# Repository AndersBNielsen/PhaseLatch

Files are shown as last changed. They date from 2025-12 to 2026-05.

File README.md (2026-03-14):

# PhaseLatch

PhaseLatch – 6502-Interfaced High-Speed ADC for Experimental SDR

Blog post & video: https://abnielsen.com/2025/12/24/6502-and-a-20mhz-adc-takes-up-the-challenge/

PhaseLatch is an open-source hardware project that explores how far a classic MOS 6502-class CPU can be pushed into modern signal-processing territory. The board implements a dual-channel, 10-bit, 20 MSPS analog-to-digital converter with a straight binary parallel output, allowing the ADC to be memory-mapped directly onto a 6502 (8 bit) data bus.

Unlike typical SDR designs that rely on high-performance microcontrollers or FPGAs, PhaseLatch intentionally interfaces high-speed conversion hardware with a severely resource-constrained 8-bit CPU. This makes it a platform for experimenting with timing limits, bus contention, memory expansion, and minimalist DSP techniques such as Goertzel tone detection executed entirely on the 6502.

The board is designed as a modular Arduino-shield-style form factor and is intended to stack with the PhaseLoom IQ mixer and the 65uino 6502 system. Direct access to the CPU address, data, and control signals enables single-instruction ADC reads and deterministic sampling under software control.

PhaseLatch is not intended to achieve full theoretical ADC bandwidth on a 6502. Instead, it serves as a practical exploration of real-world limitations, architectural trade-offs, and creative signal-processing approaches on vintage computing hardware.

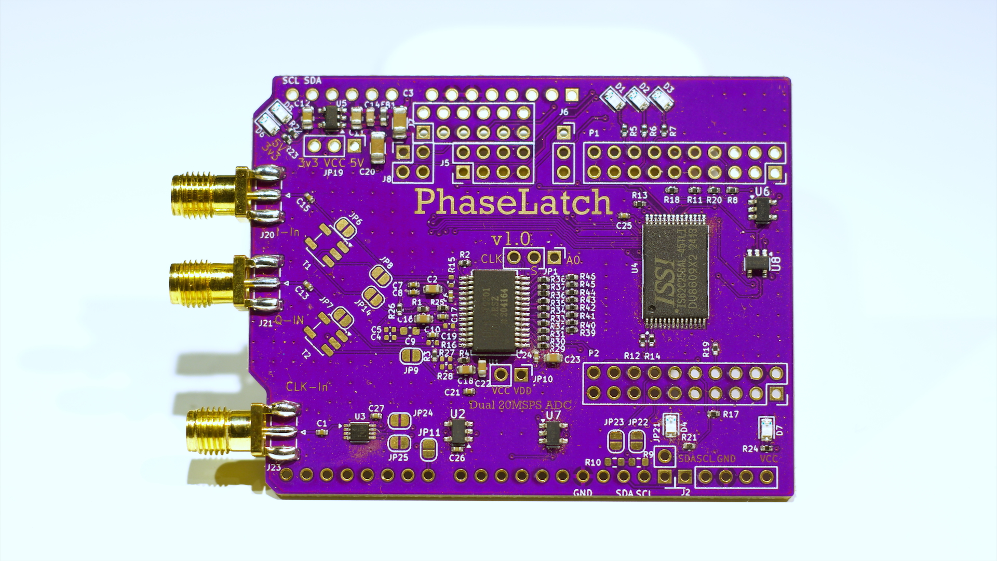
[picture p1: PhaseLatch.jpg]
PhaseLatch board photo


## Purchase

Interested in owning a PhaseLatch?  
[Buy one here](https://www.imania.dk/index.php?cPath=204&sort=5a&language=en).

## How to Use
[6502 source code still lives over on the 65uino project](https://github.com/AndersBNielsen/65uino/)

The main 65uino firmware currently comes with support for the PhaseLatch built in. Time of writing, use the SDR branch. 

To get the full bandwidth out of PhaseLatch, it can also be used with an **FX2LP** USB streaming board instead of the **65uino**.

## Software
The `software/` folder contains the USB streamer firmware + host-side tools for getting PhaseLatch data into SDR software.

- [software/README.md](software/README.md): Overview, build instructions, and a demo cheat sheet.
- [software/firmware/](software/firmware/): FX2/FX2LP firmware (USB streaming).
- [software/host/](software/host/): Host utilities (USB reader, format conversion, DC / IQ correction).
- [software/examples/](software/examples/): Example pipelines (including streaming to `/tmp/iq.fifo` for Gqrx).
- [software/doc/](software/doc/): Notes on wiring and rate planning.

## Using with an FX2LP (USB streaming)
PhaseLatch includes header footprints intended for wiring to an **FX2LP** dev board. The FX2LP provides USB 2.0 high‑speed bulk streaming and acts as the “bridge” from the ADC to a host PC.

At a high level the flow is:
- FX2LP firmware streams raw samples over USB
- host reads via libusb and converts to CF32
- stream is written to `/tmp/iq.fifo` so **Gqrx** can open it

Start with the guide in `software/README.md`, then use `software/examples/pipeline.sh` for a one-command stream to `/tmp/iq.fifo`.

## Getting a PCB

## Production & Manufacturing
- The `jlcpcb/gerber/` folder contains all necessary files for PCB fabrication.
- The `production_files/` folder includes:
  - `BOM-PhaseLatch.csv`: Bill of Materials
  - `CPL-PhaseLatch.csv`: Component Placement List
  - `GERBER-PhaseLatch.zip`: Zipped Gerber files for easy upload

This project is kindly sponsored by JLCPCB. They offer cheap, professional looking PCBs and super fast delivery.

Step 1: Get the gerber file zip package from the /hardware folder

Step 2: Upload to JLCPCB [https://jlcpcb.com/?from=Anders_N](https://jlcpcb.com/?from=Anders_N)

Upload

Step 3: Pick your color, surface finish and order.

Select settings

Save your choice

You can use these affiliate links to get a board for $2 and also get $54 worth of New User Coupons at: https://jlcpcb.com/?from=Anders_N

And in case you also want to order a 3D-printed case you can use this link. 
How to Get a $7 3D Printing Coupon: [https://3d.jlcpcb.com/?from=Anders3DP](https://jlc3dp.com/?from=Anders_N)

---

For more details, technical explanations, and the full story behind PhaseLoom, check out the project video and documentation. Special thanks to JLCPCB and Fnirsi for supporting the development of this project!

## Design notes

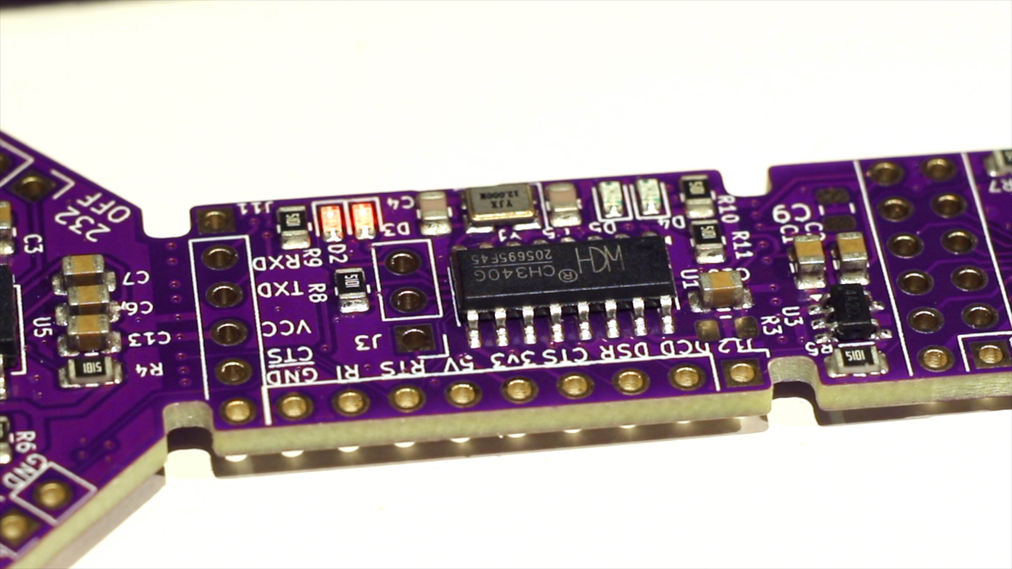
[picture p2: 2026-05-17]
U.S.A. Rev1.jpg

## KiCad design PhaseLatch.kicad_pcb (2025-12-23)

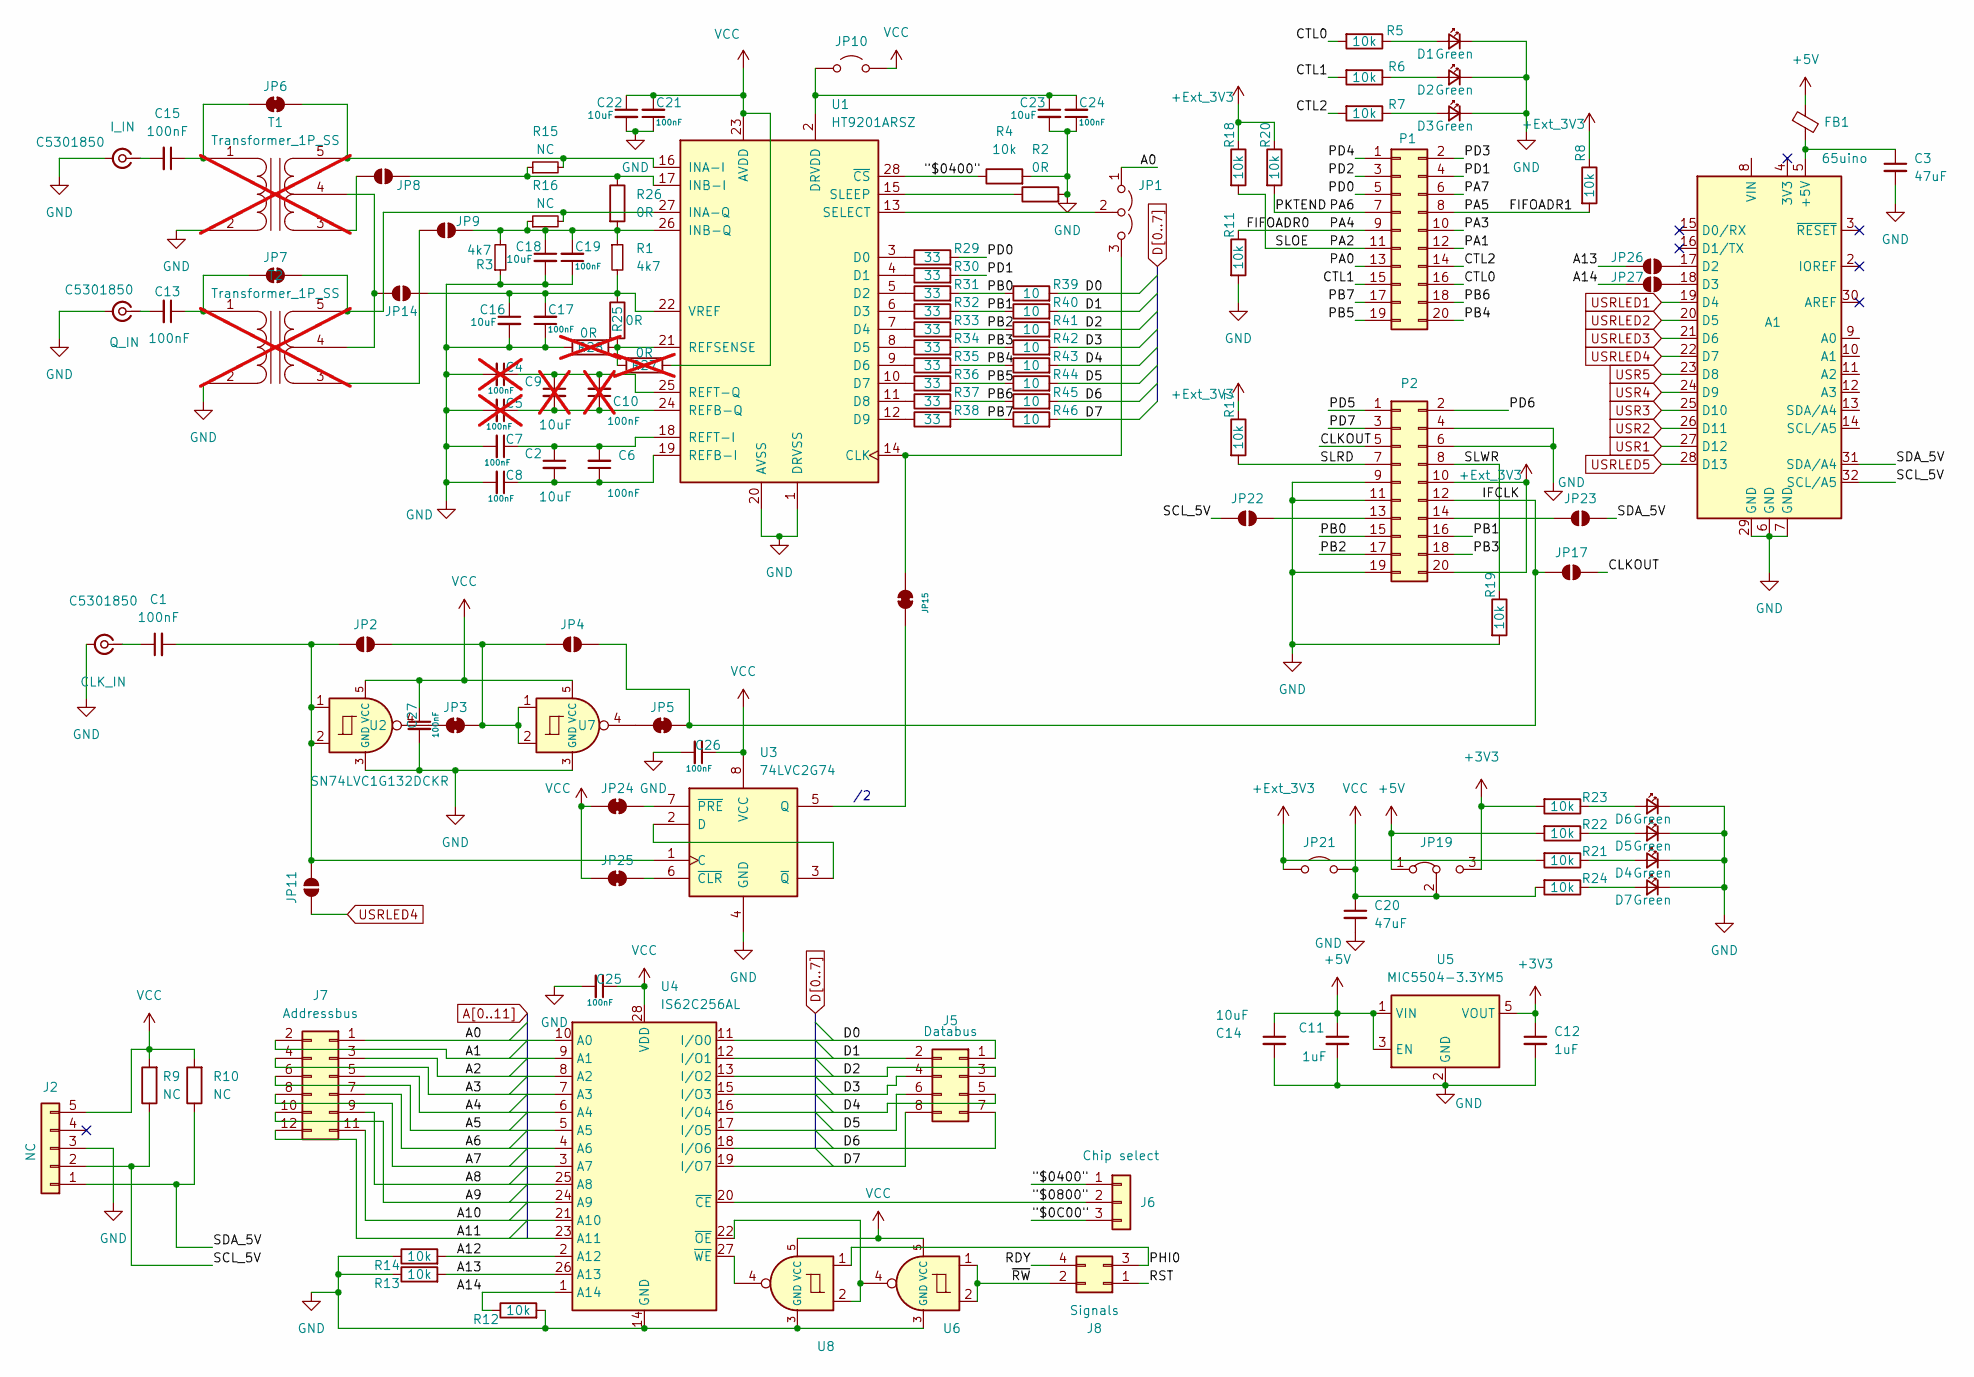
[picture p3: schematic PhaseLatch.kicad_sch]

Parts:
A1: 65uino; Arduino_UNO_R3
C1, C6, C7, C8, C13, C15, C17, C19, C21, C24, C25, C26, C27: 100nF; C_0402_1005Metric; LCSC C1525
C2, C14, C16, C18, C22, C23: 10uF; C_0603_1608Metric; LCSC C96446
C3, C20: 47uF; C_1206_3216Metric; LCSC C96123
C4, C5, C10: 100nF; C_0402_1005Metric; LCSC C1525; not fitted
C9: 10uF; C_0603_1608Metric; LCSC C96446; not fitted
C11, C12: 1uF; C_0805_2012Metric; LCSC C28323
D1, D2, D3, D4, D5, D6, D7: Green; LED_0805_2012Metric; LCSC C2297
FB1: FerriteBead_Small; L_0603_1608Metric; LCSC C14709
J2: NC; PinHeader_1x05_P2.54mm_Vertical
J5: Databus; PinHeader_2x04_P2.54mm_Vertical
J6: Chip select; PinSocket_1x03_P2.54mm_Vertical
J7: Addressbus; PinHeader_2x06_P2.54mm_Vertical
J8: Signals; PinHeader_2x02_P2.54mm_Vertical
J20: I_IN; SMA_Samtec_SMA-J-P-H-ST-EM1_EdgeMount; LCSC C5301850
J21: Q_IN; SMA_Samtec_SMA-J-P-H-ST-EM1_EdgeMount; LCSC C5301850
J23: CLK_IN; SMA_Samtec_SMA-J-P-H-ST-EM1_EdgeMount; LCSC C5301850
JP1: Jumper_3_Open; PinHeader_1x03_P2.54mm_Vertical
JP2, JP4, JP8, JP9, JP11, JP14, JP17, JP22, JP23, JP26, JP27: SolderJumper_2_Open; SolderJumper-2_P1.3mm_Open_RoundedPad1.0x1.5mm
JP3, JP5, JP6, JP7, JP15, JP24, JP25: SolderJumper-2_P1.3mm_Bridged_RoundedPad1.0x1.5mm
JP10, JP21: Jumper_2_Open; PinHeader_1x02_P2.54mm_Vertical
JP19: Jumper_3_Bridged12; PinHeader_1x03_P2.54mm_Vertical
P1, P2: Conn_02x10_Odd_Even; PinSocket_2x10_P2.54mm_Vertical
R1, R3: 4k7; R_0402_1005Metric; LCSC C25900
R2, R25, R26: 0R; R_0402_1005Metric
R4, R5, R6, R7, R8, R11, R12, R13, R14, R17, R18, R19, R20, R21, R22, R23, R24: 10k; R_0402_1005Metric; LCSC C25744
R9, R10: NC; R_0603_1608Metric
R15, R16: NC; R_0402_1005Metric
R27, R28: 0R; R_0402_1005Metric; not fitted
R29, R30, R31, R32, R33, R34, R35, R36, R37, R38: 33; R_0402_1005Metric; LCSC C25105
R39, R40, R41, R42, R43, R44, R45, R46: 10; R_0402_1005Metric; LCSC C25077
T1, T2: Transformer_1P_SS; Transformer_MiniCircuits_AT224-1A-AltPinout; not fitted
U1: HT9201ARSZ; SSOP-28_5.3x10.2mm_P0.65mm; LCSC C3019546
U2, U6, U7, U8: SN74LVC1G132DCKR; SOT-23-5; LCSC C205992
U3: 74LVC2G74; VSSOP-8_2.3x2mm_P0.5mm; LCSC C70285
U4: IS62C256AL; TSOP-I-28_11.8x8mm_P0.55mm; LCSC C47143
U5: MIC5504-3.3YM5; SOT-23-5; LCSC C3021093

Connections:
+3V3: C12.1, JP19.3 (B), R23.2, U5.5 (VOUT)
+5V: C11.1, C14.1, FB1.1, JP19.1 (A), R22.2, U5.1 (VIN), U5.3 (EN)
+Ext_3V3: JP21.1 (A), P2.10, P2.20, R8.1, R17.1, R18.1, R20.1, R21.2
/"$0C00": J6.3
/"$0400": J6.1, R4.1, U1.28 (~CS)
/"$0800": J6.2, U4.20 (~CE)
/A12: R14.2, U4.2 (A12)
/A13: JP26.1 (A), R13.2, U4.26 (A13)
/A14: JP27.1 (A), R12.1, U4.1 (A14)
/CLKOUT: JP17.2 (B), P2.5
/CTL0: P1.16, R5.2
/CTL1: P1.15, R6.2
/CTL2: P1.14, R7.2
/FIFOADR0: P1.9, R11.1
/FIFOADR1: P1.8, R8.2
/IFCLK: JP4.2 (B), JP5.2 (B), JP17.1 (A), P2.12
/PA0: P1.13
/PA1: P1.12
/PA2: P1.11, R18.2
/PA3: P1.10
/PA6: P1.7, R20.2
/PA7: P1.6
/PB0: P2.15, R31.2, R39.1
/PB1: P2.16, R32.2, R40.1
/PB2: P2.17, R33.2, R41.1
/PB3: P2.18, R34.2, R42.1
/PB4: P1.20, R35.2, R43.1
/PB5: P1.19, R36.2, R44.1
/PB6: P1.18, R37.2, R45.1
/PB7: P1.17, R38.2, R46.1
/PD0: P1.5, R29.2
/PD1: P1.4, R30.2
/PD2: P1.3
/PD3: P1.2
/PD4: P1.1
/PD5: P2.1
/PD6: P2.2
/PD7: P2.3
/PHI0: J8.3, U8.1
/RDY: J8.4
/RST: J8.1
/SCL_5V: A1.32 (SCL/A5), J2.2, JP22.1 (A), R9.1
/SDA_5V: A1.31 (SDA/A4), J2.1, JP23.2 (B), R10.1
/SLRD: P2.7, R17.2
/SLWR: P2.8, R19.1
/~RW: J8.2, U6.1, U6.2
A0: J7.1, JP1.1 (A), U4.10 (A0)
A1: J7.2, U4.9 (A1)
A2: J7.3, U4.8 (A2)
A3: J7.4, U4.7 (A3)
A4: J7.5, U4.6 (A4)
A5: J7.6, U4.5 (A5)
A6: J7.7, U4.4 (A6)
A7: J7.8, U4.3 (A7)
A8: J7.9, U4.25 (A8)
A9: J7.10, U4.24 (A9)
A10: J7.11, U4.21 (A10)
A11: J7.12, U4.23 (A11)
D0: J5.1, R39.2, U4.11 (I/O0)
D1: J5.2, R40.2, U4.12 (I/O1)
D2: J5.3, R41.2, U4.13 (I/O2)
D3: J5.4, R42.2, U4.15 (I/O3)
D4: J5.5, R43.2, U4.16 (I/O4)
D5: J5.6, R44.2, U4.17 (I/O5)
D6: J5.7, R45.2, U4.18 (I/O6)
D7: J5.8, R46.2, U4.19 (I/O7)
GND: A1.6 (GND), A1.7 (GND), A1.29 (GND), C3.2, C4.2, C5.2, C7.2, C8.2, C11.2, C12.2, C14.2, C16.2, C17.1, C18.2, C19.1, C20.2, C21.1, C22.2, C23.2, C24.1, C25.2, C26.2, C27.2, D1.1 (K), D2.1 (K), D3.1 (K), D4.1 (K), D5.1 (K), D6.1 (K), D7.1 (K), J2.3, J20.2 (Ext), J21.2 (Ext), J23.2 (Ext), P2.4, P2.6, P2.9, P2.11, P2.19, R2.2, R3.1, R4.2, R11.2, R12.2, R13.1, R14.1, R19.2, R28.1, T1.2 (AB), T2.2 (AB), U1.1 (DRVSS), U1.20 (AVSS), U2.3 (GND), U3.4 (GND), U4.14 (GND), U5.2 (GND), U6.3 (GND), U7.3 (GND), U8.3 (GND)
unnamed: A1.5 (+5V), C3.1, FB1.2
unnamed: A1.17 (D2), JP26.2 (B)
unnamed: A1.18 (D3), JP27.2 (B)
unnamed: D1.2 (A), R5.1
unnamed: D2.2 (A), R6.1
unnamed: D3.2 (A), R7.1
unnamed: D4.2 (A), R21.1
unnamed: D5.2 (A), R22.1
unnamed: D6.2 (A), R23.1
unnamed: D7.2 (A), R24.1
unnamed: C15.2, J20.1 (In)
unnamed: C13.2, J21.1 (In)
unnamed: C1.1, J23.1 (In)
unnamed: JP1.3 (B), JP15.2 (B), U1.14 (CLK)
unnamed: JP1.2 (C), U1.13 (SELECT)
unnamed: JP2.2 (B), JP3.2 (B), JP4.1 (A), U7.1, U7.2
unnamed: JP3.1 (A), U2.4
unnamed: JP5.1 (A), U7.4
unnamed: C15.1, JP6.1 (A), T1.1 (AA)
unnamed: JP6.2 (B), R15.2, T1.5 (SB), U1.16 (INA-I)
unnamed: C13.1, JP7.1 (A), T2.1 (AA)
unnamed: JP7.2 (B), R16.2, T2.5 (SB), U1.27 (INA-Q)
unnamed: JP8.1 (A), R15.1, R26.1, U1.17 (INB-I)
unnamed: JP8.2 (B), T1.3 (SA)
unnamed: C18.1, C19.2, JP9.1 (A), R1.1, R3.2, R16.1, R26.2, U1.26 (INB-Q)
unnamed: JP9.2 (B), T2.3 (SA)
unnamed: C23.1, C24.2, JP10.1 (A), U1.2 (DRVDD)
unnamed: C1.2, JP2.1 (A), JP11.2 (B), U2.1, U2.2, U3.1 (C)
unnamed: C16.1, C17.2, JP14.1 (A), R1.2, R25.1, U1.22 (VREF)
unnamed: JP14.2 (B), T1.4 (SC), T2.4 (SC)
unnamed: JP15.1 (A), U3.5 (Q)
unnamed: JP22.2 (B), P2.13
unnamed: JP23.1 (A), P2.14
unnamed: JP24.2 (B), U3.7 (~PRE)
unnamed: JP25.2 (B), U3.6 (~CLR)
unnamed: R29.1, U1.3 (D0)
unnamed: R30.1, U1.4 (D1)
unnamed: R31.1, U1.5 (D2)
unnamed: R32.1, U1.6 (D3)
unnamed: R33.1, U1.7 (D4)
unnamed: R34.1, U1.8 (D5)
unnamed: R35.1, U1.9 (D6)
unnamed: R36.1, U1.10 (D7)
unnamed: R37.1, U1.11 (D8)
unnamed: R38.1, U1.12 (D9)
unnamed: C2.2, C6.1, C8.1, U1.19 (REFB-I)
unnamed: C5.1, C9.2, C10.1, U1.24 (REFB-Q)
unnamed: R25.2, R27.1, R28.2, U1.21 (REFSENSE)
unnamed: C2.1, C6.2, C7.1, U1.18 (REFT-I)
unnamed: C4.1, C9.1, C10.2, U1.25 (REFT-Q)
unnamed: R2.1, U1.15 (SLEEP)
unnamed: U3.2 (D), U3.3 (~Q)
unnamed: U4.22 (~OE), U6.4, U8.2
unnamed: U4.27 (~WE), U8.4
USR1: A1.27 (D12)
USR2: A1.26 (D11)
USR3: A1.25 (D10)
USR4: A1.24 (D9)
USR5: A1.23 (D8)
USRLED1: A1.19 (D4)
USRLED2: A1.20 (D5)
USRLED3: A1.21 (D6)
USRLED4: A1.22 (D7), JP11.1 (A)
USRLED5: A1.28 (D13)
VCC: C20.1, C21.2, C22.1, C25.1, C26.1, C27.1, J2.5, JP10.2 (B), JP19.2 (C), JP21.2 (B), JP24.1 (A), JP25.1 (A), R9.2, R10.2, R24.2, R27.2, U1.23 (AVDD), U2.5 (VCC), U3.8 (VCC), U4.28 (VDD), U6.5 (VCC), U7.5 (VCC), U8.5 (VCC)

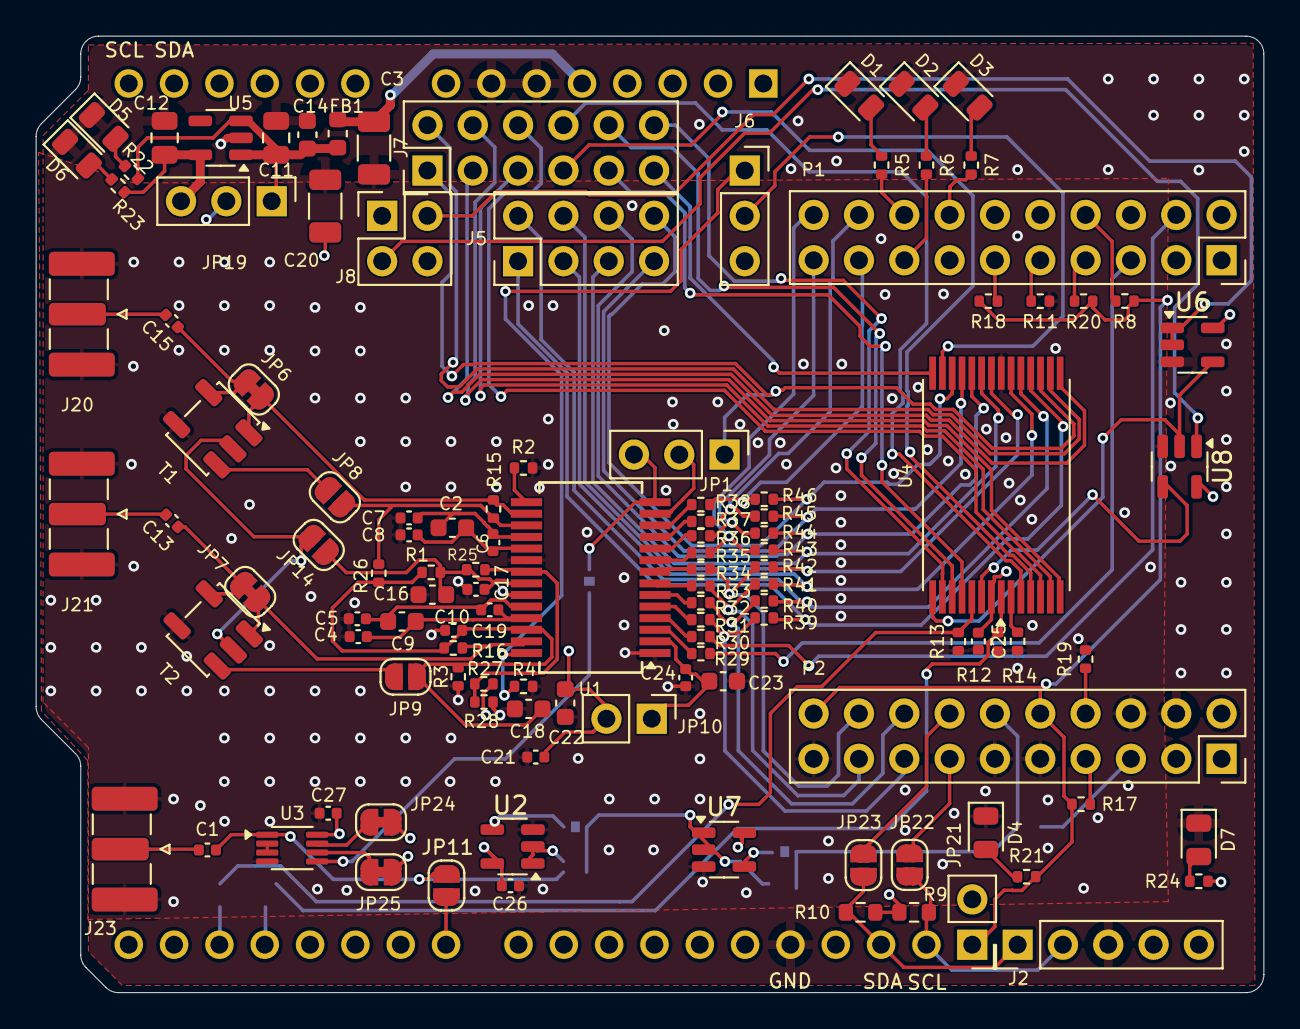
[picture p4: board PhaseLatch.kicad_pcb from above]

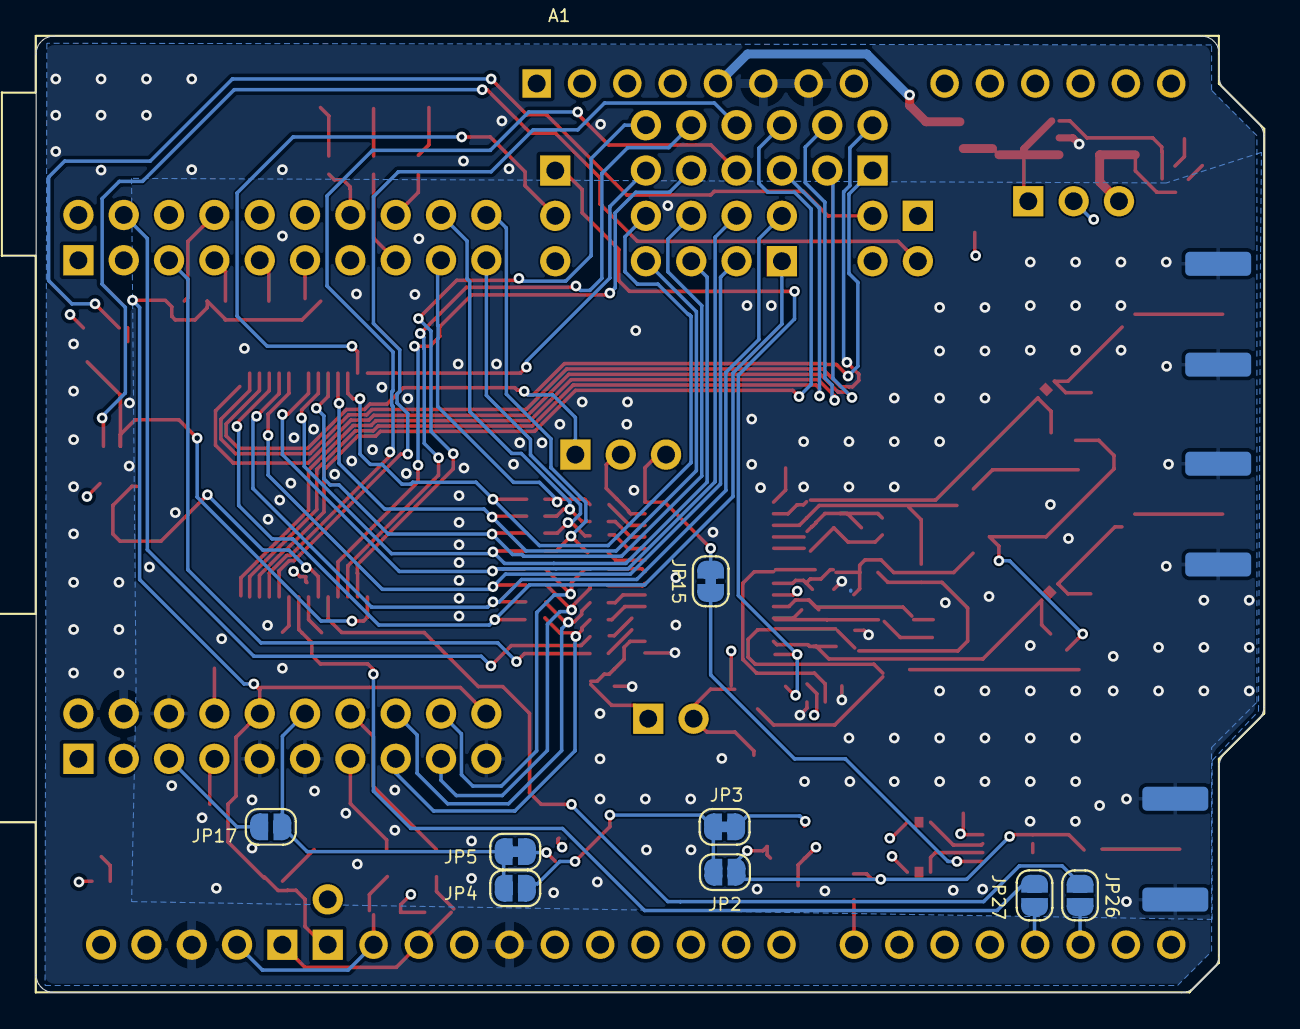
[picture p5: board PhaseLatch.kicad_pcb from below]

Board: 4 copper layers, 68.8 x 53.6 mm, 124 parts (9 on the bottom side), 110 nets.

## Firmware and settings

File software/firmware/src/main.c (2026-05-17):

// FX2 firmware: Internal IFCLK + Slave FIFO + AUTOIN (EP6 IN, 512 B)
// Build: SDCC + fx2lib headers

#include <fx2regs.h>
#include <fx2macros.h>
#include <syncdelay.h>
#include "config.h"
#include "fx2_helpers.h"
#include <setupdat.h>

// Uncomment to enable internal firmware pattern generator test (bypasses external producer)
//#define PATTERN_TEST 1

#define SD() SYNCDELAY; SYNCDELAY;

// ---------------- Vendor command support -----------------
// We preserve your original CPUCS bit comments EXACTLY as provided below.

// Simple vendor protocol (control endpoint):
//  OUT (Host->Device) commands expect 2 bytes: MASK, VALUE. Bits where MASK=1 are replaced.
//  IN  (Device->Host) commands return 1 byte.
//  Codes (avoid 0xA0–0xAF reserved by EZ-USB):
//    0xB0: SET CPUCS
//    0xB1: GET CPUCS
//    0xB2: SET IFCONFIG
//    0xB3: GET IFCONFIG
//    0xB4: SET PORTA (IOA)
//    0xB5: GET PORTA (IOA)
//    0xB6: SET OEA
//    0xB7: GET OEA
//    0xB8: GET EP6CS
//    0xB9: GET PINFLAGSAB
//    0xBA: GET PINFLAGSCD
//    0xBB: GET IFCONFIG snapshot (captured right after firmware init)
//    0xBC: I2C single-byte register write (OUT, no payload, wValueL=7-bit slave addr, wIndexL=register, wIndexH=value)
//    0xBD: I2C single-byte register read  (IN payload: [status, value], wValueL=7-bit slave addr, wIndexL=register)
//    0xBE: GET last I2C status
//    0xBF: I2C block write (OUT payload: [start_reg, data0, data1, ...], wValueL=7-bit slave addr)
//    0xC0: SET sample rate using SI5351 CLK2 = 2 * Fs (OUT, no payload, wValue:wIndex = 32-bit Fs in Hz)
//    0xC1: I2C block read (IN payload: [status, data...], wValueL=7-bit slave addr, wIndexL=start register, wLength=1+count)
//    0xC2: GET FX2 startup SI5351 CLK2 profile (IN payload: [reg0,val0,reg1,val1,...])
//    0xC3: GET EP2468STAT
//    0xC4: GET EP6CFG
//    0xC5: GET EP6FIFOCFG
//    0xC6: GET PORTACFG
//    0xC7: GET FIFOPINPOLAR
//    0xC8: GET EP2FIFOFLGS
//    0xC9: GET EP4FIFOFLGS
//    0xCA: GET EP6FIFOFLGS
//    0xCB: GET EP8FIFOFLGS

// Use the shared helper macro for masked writes
// FX2_MASKED_WRITE(reg, mask, value)

#define I2C_STATUS_OK         0x00
#define I2C_STATUS_TIMEOUT    0x01
#define I2C_STATUS_BERR       0x02
#define I2C_STATUS_ADDR_NACK  0x04
#define I2C_STATUS_DATA_NACK  0x08
#define I2C_STATUS_BAD_PARAM  0x10

static BYTE last_i2c_status = I2C_STATUS_OK;

static const BYTE si5351_init_data[] = {
    3, 0xF8,
    16, 0x80, 17, 0x80, 18, 0xC0, 19, 0x80,
    20, 0x80, 21, 0x80, 22, 0x80, 23, 0x80,
    26, 0x00, 27, 0x01, 28, 0x00, 29, 0x0C,
    30, 0x00, 31, 0x00, 32, 0x00, 33, 0x00,
    34, 0x00, 35, 0x01, 36, 0x00, 37, 0x06,
    38, 0x00, 39, 0x00, 40, 0x00, 41, 0x00,
    42, 0x00, 43, 0x01, 44, 0x00, 45, 0x30,
    46, 0x00, 47, 0x00, 48, 0x00, 49, 0x00,
    50, 0x00, 51, 0x01, 52, 0x00, 53, 0x30,
    54, 0x00, 55, 0x00, 56, 0x00, 57, 0x00,
    58, 0x00, 59, 0x01, 60, 0x00, 61, 0x03,
    62, 0x00, 63, 0x00, 64, 0x00, 65, 0x00,
    165, 100,
    177, 0xA0,
    3, 0xF8,
    16, 0x0F, 17, 0x0F, 18, 0x6C,
};

static const BYTE si5351_frq_30005000_pll[] = {
    0x00, 0xFA, 0x00, 0x0A, 0x00, 0x00, 0x00, 0x80,
};

static const BYTE si5351_frq_30005000_ms[] = {
    0x00, 0x01, 0x00, 0x08, 0x00, 0x00, 0x00, 0x00,
};

static const BYTE si5351_startup_clk2_profile[] = {
    3, 0xF8,
    16, 0x0F,
    17, 0x0F,
    18, 0x6C,
    34, 0x00,
    35, 0x01,
    36, 0x00,
    37, 0x06,
    38, 0x00,
    39, 0x00,
    40, 0x00,
    41, 0x00,
    58, 0x00,
    59, 0x01,
    60, 0x00,
    61, 0x03,
    62, 0x00,
    63, 0x00,
    64, 0x00,
    65, 0x00,
    165, 20,
    177, 0x20,
};

static void i2c_status_clear(void) {
    last_i2c_status = I2C_STATUS_OK;
}

static void i2c_recover_bus(void) {
    WORD timeout = 65535;

    I2CS |= bmSTOP;
    while ((I2CS & bmSTOP) && --timeout) { }

    I2CTL = 0x00;
}

static BOOL i2c_wait_done(void) {
    WORD timeout = 65535;
    while (!(I2CS & bmDONE) && --timeout) { }
    if (timeout == 0) {
        last_i2c_status |= I2C_STATUS_TIMEOUT;
        i2c_recover_bus();
        return FALSE;
    }
    if (I2CS & bmBERR) {
        last_i2c_status |= I2C_STATUS_BERR;
        i2c_recover_bus();
        return FALSE;
    }
    return TRUE;
}

static void i2c_stop_nowait(void) {
    I2CS |= bmSTOP;
}

static void si5351_delay_long(void) {
    WORD outer;
    BYTE inner;

    for (outer = 0; outer != 0x0200; ++outer) {
        for (inner = 0; inner != 0xFF; ++inner) { }
    }
}

static BOOL i2c_wait_stop(void) {
    WORD timeout = 65535;
    while ((I2CS & bmSTOP) && --timeout) { }
    if (timeout == 0) {
        last_i2c_status |= I2C_STATUS_TIMEOUT;
        return FALSE;
    }
    return TRUE;
}

static BOOL fx2_i2c_write(BYTE addr, WORD len1, BYTE *buf1, WORD len2, BYTE *buf2) {
    WORD cur_byte;
    WORD total_bytes = len1 + len2;
    BYTE retry_count = 3;

    i2c_status_clear();
    if (total_bytes == 0) {
        return TRUE;
    }

start:
    cur_byte = 0;
    I2CS |= bmSTART;
    if (I2CS & bmBERR) {
        i2c_recover_bus();
        if (--retry_count == 0) {
            last_i2c_status |= I2C_STATUS_BERR;
            return FALSE;
        }
        goto start;
    }

    I2DAT = (BYTE)(addr << 1);
    if (!i2c_wait_done()) {
        if ((last_i2c_status & I2C_STATUS_BERR) && --retry_count) goto start;
        i2c_stop_nowait();
        i2c_wait_stop();
        return FALSE;
    }

    if (!(I2CS & bmACK)) {
        last_i2c_status |= I2C_STATUS_ADDR_NACK;
        i2c_stop_nowait();
        i2c_wait_stop();
        return FALSE;
    }

    while (cur_byte < total_bytes) {
        I2DAT = (cur_byte < len1) ? buf1[cur_byte] : buf2[cur_byte - len1];
        ++cur_byte;

        if (!i2c_wait_done()) {
            if ((last_i2c_status & I2C_STATUS_BERR) && --retry_count) goto start;
            i2c_stop_nowait();
            i2c_wait_stop();
            return FALSE;
        }

        if (!(I2CS & bmACK)) {
            last_i2c_status |= I2C_STATUS_DATA_NACK;
            i2c_stop_nowait();
            i2c_wait_stop();
            return FALSE;
        }
    }

    i2c_stop_nowait();
    return i2c_wait_stop();
}

static BOOL fx2_i2c_read(BYTE addr, WORD len, BYTE *buf) {
    BYTE tmp;
    WORD cur_byte;
    BYTE retry_count = 3;

    i2c_status_clear();
    if (len == 0) {
        return TRUE;
    }

start:
    cur_byte = 0;
    I2CS |= bmSTART;
    if (I2CS & bmBERR) {
        i2c_recover_bus();
        if (--retry_count == 0) {
            last_i2c_status |= I2C_STATUS_BERR;
            return FALSE;
        }
        goto start;
    }

    I2DAT = (BYTE)((addr << 1) | 1);
    if (!i2c_wait_done()) {
        if ((last_i2c_status & I2C_STATUS_BERR) && --retry_count) goto start;
        i2c_stop_nowait();
        i2c_wait_stop();
        return FALSE;
    }

    if (!(I2CS & bmACK)) {
        last_i2c_status |= I2C_STATUS_ADDR_NACK;
        i2c_stop_nowait();
        i2c_wait_stop();
        return FALSE;
    }

    if (len == 1) {
        I2CS |= bmLASTRD;
    }

    tmp = I2DAT;
    (void)tmp;

    while (len > cur_byte + 1) {
        if (!i2c_wait_done()) {
            if ((last_i2c_status & I2C_STATUS_BERR) && --retry_count) goto start;
            i2c_stop_nowait();
            i2c_wait_stop();
            return FALSE;
        }

        if (len == cur_byte + 2) {
            I2CS |= bmLASTRD;
        }

        buf[cur_byte++] = I2DAT;
    }

    if (!i2c_wait_done()) {
        if ((last_i2c_status & I2C_STATUS_BERR) && --retry_count) goto start;
        i2c_stop_nowait();
        i2c_wait_stop();
        return FALSE;
    }

    i2c_stop_nowait();
    buf[cur_byte] = I2DAT;
    return i2c_wait_stop();
}

static BOOL fx2_i2c_write_reg(BYTE addr, BYTE reg, BYTE value) {
    BYTE reg_buf[1];
    BYTE val_buf[1];
    reg_buf[0] = reg;
    val_buf[0] = value;
    return fx2_i2c_write(addr, 1, reg_buf, 1, val_buf);
}

static BOOL fx2_i2c_read_reg_once(BYTE addr, BYTE reg, BYTE *value) {
    BYTE tmp;
    BYTE retry_count = 3;

    i2c_status_clear();

start:
    I2CS |= bmSTART;
    if (I2CS & bmBERR) {
        i2c_recover_bus();
        if (--retry_count == 0) {
            last_i2c_status |= I2C_STATUS_BERR;
            return FALSE;
        }
        goto start;
    }

    I2DAT = (BYTE)(addr << 1);
    if (!i2c_wait_done()) {
        if ((last_i2c_status & I2C_STATUS_BERR) && --retry_count) goto start;
        i2c_stop_nowait();
        i2c_wait_stop();
        return FALSE;
    }
    if (!(I2CS & bmACK)) {
        last_i2c_status |= I2C_STATUS_ADDR_NACK;
        i2c_stop_nowait();
        i2c_wait_stop();
        return FALSE;
    }

    I2DAT = reg;
    if (!i2c_wait_done()) {
        if ((last_i2c_status & I2C_STATUS_BERR) && --retry_count) goto start;
        i2c_stop_nowait();
        i2c_wait_stop();
        return FALSE;
    }
    if (!(I2CS & bmACK)) {
        last_i2c_status |= I2C_STATUS_DATA_NACK;
        i2c_stop_nowait();
        i2c_wait_stop();
        return FALSE;
    }

    I2CS |= bmSTART;
    if (I2CS & bmBERR) {
        i2c_recover_bus();
        if (--retry_count == 0) {
            last_i2c_status |= I2C_STATUS_BERR;
            return FALSE;
        }
        goto start;
    }

    I2DAT = (BYTE)((addr << 1) | 1);
    if (!i2c_wait_done()) {
        if ((last_i2c_status & I2C_STATUS_BERR) && --retry_count) goto start;
        i2c_stop_nowait();
        i2c_wait_stop();
        return FALSE;
    }
    if (!(I2CS & bmACK)) {
        last_i2c_status |= I2C_STATUS_ADDR_NACK;
        i2c_stop_nowait();
        i2c_wait_stop();
        return FALSE;
    }

    I2CS |= bmLASTRD;
    tmp = I2DAT;
    (void)tmp;

    if (!i2c_wait_done()) {
        if ((last_i2c_status & I2C_STATUS_BERR) && --retry_count) goto start;
        i2c_stop_nowait();
        i2c_wait_stop();
        return FALSE;
    }

    i2c_stop_nowait();
    *value = I2DAT;
    return i2c_wait_stop();
}

static BOOL fx2_i2c_read_reg(BYTE addr, BYTE reg, BYTE *value) {
    BYTE discard;

    if (!fx2_i2c_read_reg_once(addr, reg, &discard)) {
        return FALSE;
    }

    return fx2_i2c_read_reg_once(addr, reg, value);
}

static BOOL fx2_i2c_read_block_reg(BYTE addr, BYTE reg, BYTE len, BYTE *buf) {
    BYTE tmp;
    BYTE cur_byte;
    BYTE retry_count = 3;

    i2c_status_clear();
    if (len == 0) {
        return TRUE;
    }

start:
    I2CS |= bmSTART;
    if (I2CS & bmBERR) {
        i2c_recover_bus();
        if (--retry_count == 0) {
            last_i2c_status |= I2C_STATUS_BERR;
            return FALSE;
        }
        goto start;
    }

    I2DAT = (BYTE)(addr << 1);
    if (!i2c_wait_done()) {
        if ((last_i2c_status & I2C_STATUS_BERR) && --retry_count) goto start;
        i2c_stop_nowait();
        i2c_wait_stop();
        return FALSE;
    }
    if (!(I2CS & bmACK)) {
        last_i2c_status |= I2C_STATUS_ADDR_NACK;
        i2c_stop_nowait();
        i2c_wait_stop();
        return FALSE;
    }

    I2DAT = reg;
    if (!i2c_wait_done()) {
        if ((last_i2c_status & I2C_STATUS_BERR) && --retry_count) goto start;
        i2c_stop_nowait();
        i2c_wait_stop();
        return FALSE;
    }
    if (!(I2CS & bmACK)) {
        last_i2c_status |= I2C_STATUS_DATA_NACK;
        i2c_stop_nowait();
        i2c_wait_stop();
        return FALSE;
    }

    I2CS |= bmSTART;
    if (I2CS & bmBERR) {
        i2c_recover_bus();
        if (--retry_count == 0) {
            last_i2c_status |= I2C_STATUS_BERR;
            return FALSE;
        }
        goto start;
    }

    I2DAT = (BYTE)((addr << 1) | 1);
    if (!i2c_wait_done()) {
        if ((last_i2c_status & I2C_STATUS_BERR) && --retry_count) goto start;
        i2c_stop_nowait();
        i2c_wait_stop();
        return FALSE;
    }
    if (!(I2CS & bmACK)) {
        last_i2c_status |= I2C_STATUS_ADDR_NACK;
        i2c_stop_nowait();
        i2c_wait_stop();
        return FALSE;
    }

    if (len == 1) {
        I2CS |= bmLASTRD;
    }

    tmp = I2DAT;
    (void)tmp;
    cur_byte = 0;

    while (len > cur_byte + 1) {
        if (!i2c_wait_done()) {
            if ((last_i2c_status & I2C_STATUS_BERR) && --retry_count) goto start;
            i2c_stop_nowait();
            i2c_wait_stop();
            return FALSE;
        }

        if (len == cur_byte + 2) {
            I2CS |= bmLASTRD;
        }

        buf[cur_byte++] = I2DAT;
    }

    if (!i2c_wait_done()) {
        if ((last_i2c_status & I2C_STATUS_BERR) && --retry_count) goto start;
        i2c_stop_nowait();
        i2c_wait_stop();
        return FALSE;
    }

    i2c_stop_nowait();
    buf[cur_byte] = I2DAT;
    return i2c_wait_stop();
}

static BOOL si5351_write_pairs(const BYTE *pairs, BYTE pair_count) {
    BYTE idx;

    for (idx = 0; idx != pair_count; ++idx) {
        if (!fx2_i2c_write_reg(0x60, pairs[(WORD)idx * 2], pairs[(WORD)idx * 2 + 1])) {
            return FALSE;
        }
    }

    return TRUE;
}

static BOOL si5351_profile_matches(const BYTE *pairs, BYTE pair_count) {
    BYTE idx;
    BYTE value;

    for (idx = 0; idx != pair_count; ++idx) {
        if (!fx2_i2c_read_reg(0x60, pairs[(WORD)idx * 2], &value)) {
            return FALSE;
        }
        if (value != pairs[(WORD)idx * 2 + 1]) {
            return FALSE;
        }
    }

    return TRUE;
}

static BOOL si5351_program_default_profile(void) {
    BYTE idx;

    if (si5351_profile_matches(si5351_startup_clk2_profile, (BYTE)(sizeof(si5351_startup_clk2_profile) / 2))) {
        return TRUE;
    }

    if (!si5351_write_pairs(si5351_init_data, (BYTE)(sizeof(si5351_init_data) / 2))) return FALSE;
    if (!fx2_i2c_write_reg(0x60, 3, 0xFF)) return FALSE;

    for (idx = 0; idx != 8; ++idx) {
        if (!fx2_i2c_write_reg(0x60, (BYTE)(26 + idx), si5351_frq_30005000_pll[idx])) return FALSE;
    }

    for (idx = 0; idx != 16; ++idx) {
        if (!fx2_i2c_write_reg(0x60, (BYTE)(42 + idx), si5351_frq_30005000_ms[idx & 7])) return FALSE;
    }

    if (!fx2_i2c_write_reg(0x60, 165, 20)) return FALSE;
    si5351_delay_long();
    if (!fx2_i2c_write_reg(0x60, 177, 0x20)) return FALSE;
    si5351_delay_long();
    if (!fx2_i2c_write_reg(0x60, 3, 0xF8)) return FALSE;

    return TRUE;
}

static BOOL si5351_write_clk2_integer_sample_rate(DWORD sample_hz) {
    static BYTE ms2_regs[8];
    static BYTE pllb_regs[8];
    static BYTE reg34 = 34;
    static BYTE reg58 = 58;
    BYTE enable_reg;
    DWORD clk2_hz;
    DWORD pll_mult;
    DWORD pll_hz;
    DWORD clk2_full;
    DWORD divider;
    DWORD p1;

    i2c_status_clear();

    if (sample_hz == 0UL) {
        last_i2c_status |= I2C_STATUS_BAD_PARAM;
        return FALSE;
    }

    clk2_full = sample_hz * 2UL;
    if (clk2_full < 1UL) {
        last_i2c_status |= I2C_STATUS_BAD_PARAM;
        return FALSE;
    }
    clk2_hz = clk2_full;

    pll_mult = 24UL;
    divider = 0UL;
    while (pll_mult <= 36UL) {
        pll_hz = 25000000UL * pll_mult;
        if ((pll_hz % clk2_hz) == 0UL) {
            divider = pll_hz / clk2_hz;
            if (divider >= 8UL && divider <= 900UL) {
                break;
            }
        }
        ++pll_mult;
    }

    if (pll_mult > 36UL) {
        last_i2c_status |= I2C_STATUS_BAD_PARAM;
        return FALSE;
    }

    p1 = 128UL * pll_mult - 512UL;
    pllb_regs[0] = 0x00;
    pllb_regs[1] = 0x01;
    pllb_regs[2] = 0x00;
    pllb_regs[3] = (BYTE)(p1 >> 8);
    pllb_regs[4] = (BYTE)p1;
    pllb_regs[5] = 0x00;
    pllb_regs[6] = 0x00;
    pllb_regs[7] = 0x00;

    p1 = 128UL * divider - 512UL;
    ms2_regs[0] = 0x00;
    ms2_regs[1] = 0x01;
    ms2_regs[2] = 0x00;
    ms2_regs[3] = (BYTE)(p1 >> 8);
    ms2_regs[4] = (BYTE)p1;
    ms2_regs[5] = 0x00;
    ms2_regs[6] = 0x00;
    ms2_regs[7] = 0x00;

    if (!fx2_i2c_write(0x60, 1, &reg34, 8, pllb_regs)) return FALSE;
    if (!fx2_i2c_write(0x60, 1, &reg58, 8, ms2_regs)) return FALSE;
    if (!fx2_i2c_write_reg(0x60, 18, 0x6C)) return FALSE;
    si5351_delay_long();
    if (!fx2_i2c_write_reg(0x60, 177, 0x80)) return FALSE;
    si5351_delay_long();
    if (!fx2_i2c_read_reg(0x60, 3, &enable_reg)) return FALSE;
    if (!fx2_i2c_write_reg(0x60, 3, (BYTE)(enable_reg & (BYTE)~0x04))) return FALSE;

    return TRUE;
}
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
void main(void) {
    //Bits
    //7-6: Reserved
    //5: PortCSTB
    //4-3: 00 = 12MHz, 01 = 24MHz, 10 = 48MHz, 11 = Reserved
    //2: CLKINV 
    //1: CLKOE
    //0 - reserved
    CPUCS = 0x0A;  SD(); // 24 MHz, CLKOUT enabled

    IFCONFIG = IFCONFIG_VALUE;  SYNCDELAY;
    // Capture IFCONFIG immediately after we set it
    {
        extern BYTE boot_ifconfig_snapshot;
        boot_ifconfig_snapshot = IFCONFIG;
    }
    REVCTL = 0x03;    SYNCDELAY;  // Enhanced Packet Handling (TRM recommendation for slave FIFO)

    // Configure EP6 (IN) for bulk input, quad-buffered (4*512 bytes).
    EP6CFG = 0xE0;  SYNCDELAY; // 1110 0000: VALID + IN + BULK + Quad

    // FIFO Reset sequence (TRM)
    FIFORESET = 0x80;  SYNCDELAY;  // NAK all requests
    FIFORESET = 0x02;  SYNCDELAY;  // Reset EP2
    FIFORESET = 0x04;  SYNCDELAY;  // Reset EP4
    FIFORESET = 0x06;  SYNCDELAY;  // Reset EP6
    FIFORESET = 0x08;  SYNCDELAY;  // Reset EP8
    FIFORESET = 0x00;  SYNCDELAY;  // Release NAKs

    // 8-bit FIFO samples with AUTOIN; leave WORDWIDE disabled.
    EP6FIFOCFG = 0x0C;  SYNCDELAY;

    // PORTACFG: FLAGD SLCS(*) 0 0 0 0 INT1 INT0
    PORTACFG = 0x00;  SYNCDELAY;

    // All default polarities: SLWR active low, etc.
    FIFOPINPOLAR=0x00;  SYNCDELAY;

    // AUTOIN packet commit length (512 bytes)
    EP6AUTOINLENH = 0x02; SYNCDELAY;  // MSB
    EP6AUTOINLENL = 0x00; SYNCDELAY;  // LSB

    PINFLAGSAB = 0x00; SYNCDELAY; // No special flags on Port A/B pins  
    PINFLAGSCD = 0x00; SYNCDELAY; // No special flags on Port C/D pins

    // Enable FX2 hardware I2C at 100 kHz on the dedicated SDA/SCL pins.
    I2CTL = 0x00;
    (void)si5351_program_default_profile();

    // LED on PA0 for heartbeat
    OEA |= 0x01; // PA0 output

    // Main superloop: blink + optional pattern fill (control transfers handled by fx2lib core)
    unsigned long blink = 0UL;
    for(;;) {
        // Poll for setup data so vendor commands are handled
        handle_setupdata();
        if(++blink == 40000UL) { PA0 = 1; }
        else if(blink == 80000UL) { PA0 = 0; blink = 0UL; }
#ifdef PATTERN_TEST
        if(!(EP6CS & 0x02)) { // 0x02 == FULL bit
            push_pattern_ep6();
        }
#endif
    }
}

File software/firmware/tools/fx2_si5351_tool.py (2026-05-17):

#!/usr/bin/env python3
import argparse
import math
from fractions import Fraction
import sys

import usb.core
import usb.util


VID = 0x04B4
PID = 0x8613
SI5351_ADDR = 0x60
SI5351_XTAL_HZ = 25_000_000
SI5351_PLLA_MIN_HZ = 600_000_000
SI5351_PLLA_MAX_HZ = 900_000_000
SI5351_PLLB_HZ = 400_000_000
SI5351_MAX_DENOM = 1_048_575
SI5351_MS_INT_MIN = 5
SI5351_MS_INT_MAX = 900
SI5351_PHASE_MAX = 127
SI5351_SAMPLE_PLL_INT_MIN = 24
SI5351_SAMPLE_PLL_INT_MAX = 36
SI5351_SAMPLE_MS_MIN = 8
SI5351_SAMPLE_MS_MAX = 900

REQ_I2C_WRITE1 = 0xBC
REQ_I2C_READ1 = 0xBD
REQ_I2C_STATUS = 0xBE
REQ_I2C_WRITE_BLOCK = 0xBF
REQ_SET_SAMPLE_RATE = 0xC0
REQ_I2C_READ_BLOCK = 0xC1
REQ_GET_STARTUP_PROFILE = 0xC2
REQ_GET_CPUCS = 0xB1
REQ_GET_IFCONFIG = 0xB3
REQ_GET_EP6CS = 0xB8
REQ_GET_PINFLAGSAB = 0xB9
REQ_GET_PINFLAGSCD = 0xBA
REQ_GET_IFCONFIG_SNAPSHOT = 0xBB
REQ_GET_EP2468STAT = 0xC3
REQ_GET_EP6CFG = 0xC4
REQ_GET_EP6FIFOCFG = 0xC5
REQ_GET_PORTACFG = 0xC6
REQ_GET_FIFOPINPOLAR = 0xC7
REQ_GET_EP2FIFOFLGS = 0xC8
REQ_GET_EP4FIFOFLGS = 0xC9
REQ_GET_EP6FIFOFLGS = 0xCA
REQ_GET_EP8FIFOFLGS = 0xCB

I2C_STATUS_TIMEOUT = 0x01
I2C_STATUS_BERR = 0x02
I2C_STATUS_ADDR_NACK = 0x04
I2C_STATUS_DATA_NACK = 0x08
I2C_STATUS_BAD_PARAM = 0x10

SI5351_INIT_DATA = [
    (3, 0xF8),
    (16, 0x80), (17, 0x80), (18, 0xC0), (19, 0x80),
    (20, 0x80), (21, 0x80), (22, 0x80), (23, 0x80),
    (26, 0x00), (27, 0x01), (28, 0x00), (29, 0x0C),
    (30, 0x00), (31, 0x00), (32, 0x00), (33, 0x00),
    (34, 0x00), (35, 0x01), (36, 0x00), (37, 0x06),
    (38, 0x00), (39, 0x00), (40, 0x00), (41, 0x00),
    (42, 0x00), (43, 0x01), (44, 0x00), (45, 0x30),
    (46, 0x00), (47, 0x00), (48, 0x00), (49, 0x00),
    (50, 0x00), (51, 0x01), (52, 0x00), (53, 0x30),
    (54, 0x00), (55, 0x00), (56, 0x00), (57, 0x00),
    (58, 0x00), (59, 0x01), (60, 0x00), (61, 0x03),
    (62, 0x00), (63, 0x00), (64, 0x00), (65, 0x00),
    (165, 100),
    (177, 0xA0),
    (3, 0xF8),
    (16, 0x0F), (17, 0x0F), (18, 0x6C),
]

FRQ_30005000_DATA = [0, 250, 0, 10, 0, 0, 0, 128, 0, 1, 0, 8, 0, 0, 0, 0, 20]

FREQ_TABLE = [
    (7025000,  [1, 244, 0, 10, 21, 0, 0, 124, 0, 1, 0, 41, 0, 0, 0, 0, 86]),
    (7075000,  [0, 200, 0, 10, 7, 0, 0, 8, 0, 1, 0, 40, 128, 0, 0, 0, 85]),
    (7125000,  [0, 40, 0, 10, 28, 0, 0, 32, 0, 1, 0, 40, 128, 0, 0, 0, 85]),
    (7175000,  [0, 250, 0, 10, 13, 0, 0, 206, 0, 1, 0, 40, 0, 0, 0, 0, 84]),
    (7225000,  [0, 250, 0, 10, 35, 0, 0, 82, 0, 1, 0, 40, 0, 0, 0, 0, 84]),
    (7275000,  [3, 232, 0, 10, 19, 0, 2, 72, 0, 1, 0, 39, 128, 0, 0, 0, 83]),
    (30005000, FRQ_30005000_DATA),
    (89750000, [136, 181, 192, 10, 144, 8, 5, 176, 0, 1, 0, 1, 128, 0, 0, 0, 7]),
    (93350000, [1, 244, 0, 11, 17, 0, 1, 76, 0, 1, 0, 1, 128, 0, 0, 0, 7]),
    (97850000, [1, 244, 0, 11, 178, 0, 1, 216, 0, 1, 0, 1, 128, 0, 0, 0, 7]),
    (98150000, [43, 58, 224, 11, 189, 9, 220, 174, 0, 1, 0, 1, 128, 0, 0, 0, 7]),
    (100250000,[0, 50, 0, 10, 7, 0, 0, 34, 0, 1, 0, 1, 0, 0, 0, 0, 6]),
    (102750000,[0, 50, 0, 10, 84, 0, 0, 24, 0, 1, 0, 1, 0, 0, 0, 0, 6]),
    (104550000,[0, 250, 0, 10, 139, 0, 0, 194, 0, 1, 0, 1, 0, 0, 0, 0, 6]),
    (106050000,[0, 250, 0, 10, 185, 0, 0, 214, 0, 1, 0, 1, 0, 0, 0, 0, 6]),
    (144850000,[0, 100, 0, 12, 124, 0, 0, 16, 0, 1, 0, 0, 128, 0, 0, 0, 5]),
]

EXPECTED_STARTUP_CLK2_PROFILE = [
    (3, 0xF8),
    (16, 0x0F),
    (17, 0x0F),
    (18, 0x6C),
    (34, 0x00),
    (35, 0x01),
    (36, 0x00),
    (37, 0x06),
    (38, 0x00),
    (39, 0x00),
    (40, 0x00),
    (41, 0x00),
    (58, 0x00),
    (59, 0x01),
    (60, 0x00),
    (61, 0x03),
    (62, 0x00),
    (63, 0x00),
    (64, 0x00),
    (65, 0x00),
    (165, 20),
    (177, 0x20),
]


def parse_int(text: str) -> int:
    return int(text, 0)


def status_to_text(status: int) -> str:
    if status == 0:
        return "OK"
    parts = []
    if status & I2C_STATUS_TIMEOUT:
        parts.append("timeout")
    if status & I2C_STATUS_BERR:
        parts.append("bus-error")
    if status & I2C_STATUS_ADDR_NACK:
        parts.append("addr-nack")
    if status & I2C_STATUS_DATA_NACK:
        parts.append("data-nack")
    return ",".join(parts) if parts else f"0x{status:02x}"


def open_device(vid: int, pid: int):
    dev = usb.core.find(idVendor=vid, idProduct=pid)
    if dev is None:
        raise SystemExit(f"FX2 device {vid:04x}:{pid:04x} not found")

    try:
        dev.set_configuration()
    except usb.core.USBError:
        pass

    try:
        cfg = dev.get_active_configuration()
        intf = cfg[(0, 0)]
        try:
            if dev.is_kernel_driver_active(intf.bInterfaceNumber):
                dev.detach_kernel_driver(intf.bInterfaceNumber)
        except (NotImplementedError, usb.core.USBError):
            pass
        try:
            usb.util.claim_interface(dev, intf.bInterfaceNumber)
        except usb.core.USBError:
            pass
    except usb.core.USBError:
        pass

    return dev


def try_ctrl_transfer(dev, request_types, request, value, index, data_or_length, timeout=2000):
    last_exc = None
    for request_type in request_types:
        try:
            return dev.ctrl_transfer(request_type, request, value, index, data_or_length, timeout=timeout)
        except usb.core.USBError as exc:
            last_exc = exc
    if last_exc is not None:
        raise last_exc
    raise RuntimeError("no control transfer request types provided")


def get_i2c_status(dev) -> int:
    last_exc = None
    for _ in range(5):
        try:
            data = try_ctrl_transfer(dev, (0xC0, 0xC1, 0xC2), REQ_I2C_STATUS, 0, 0, 1, timeout=2000)
            if len(data) < 1:
                raise RuntimeError("I2C status request returned no data")
            data = try_ctrl_transfer(dev, (0xC0, 0xC1, 0xC2), REQ_I2C_STATUS, 0, 0, 1, timeout=2000)
            if len(data) < 1:
                raise RuntimeError("I2C status request returned no data")
            return int(data[0])
        except (RuntimeError, usb.core.USBError) as exc:
            last_exc = exc
    if last_exc is not None:
        raise last_exc
    raise RuntimeError("I2C status request failed")


def get_vendor_byte(dev, request: int) -> int:
    last_exc = None
    for _ in range(5):
        try:
            data = try_ctrl_transfer(dev, (0xC0, 0xC1, 0xC2), request, 0, 0, 1, timeout=2000)
            if len(data) < 1:
                raise RuntimeError(f"vendor request 0x{request:02X} returned no data")
            data = try_ctrl_transfer(dev, (0xC0, 0xC1, 0xC2), request, 0, 0, 1, timeout=2000)
            if len(data) < 1:
                raise RuntimeError(f"vendor request 0x{request:02X} returned no data")
            return int(data[0])
        except (RuntimeError, usb.core.USBError) as exc:
            last_exc = exc
    if last_exc is not None:
        raise last_exc
    raise RuntimeError(f"vendor request 0x{request:02X} failed")
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

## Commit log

2025-09-19 Ready for review
    [PhaseLatch.kicad_pcb, PhaseLatch.kicad_sch]
2025-09-19 Mods from review
    [PhaseLatch.kicad_pcb]
2025-09-19 Final touches
    [PhaseLatch.kicad_pcb]
2025-12-23 Version 1.1 - correct RAM footprint
    [PhaseLatch.kicad_pcb, PhaseLatch.kicad_sch]
2026-05-17 feat: add si5351 control via fx2lp
    [PhaseLatch.kicad_sch]
